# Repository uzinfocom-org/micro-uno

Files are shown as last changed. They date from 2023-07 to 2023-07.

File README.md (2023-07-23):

# Micro UNO

Birinchi mikrokompyuterlar yoki umuman miktoprotsessorlarning qanday ishlashini o'rganmoqchi bo'lsangiz unda ushbu konstruksiya siz uchun ayni muddao. Konstruksiya uchun barcha kerakli ehtiyot qismlarni O'zbekiston sharoitida muammosiz topishingiz mumkin. Shuningdek 3D printerda chop etish uchun modellar ham biriktirilgan.

Youtube video: [https://www.youtube.com/watch?v=Z8Tm94-23g4](https://www.youtube.com/watch?v=Z8Tm94-23g4)

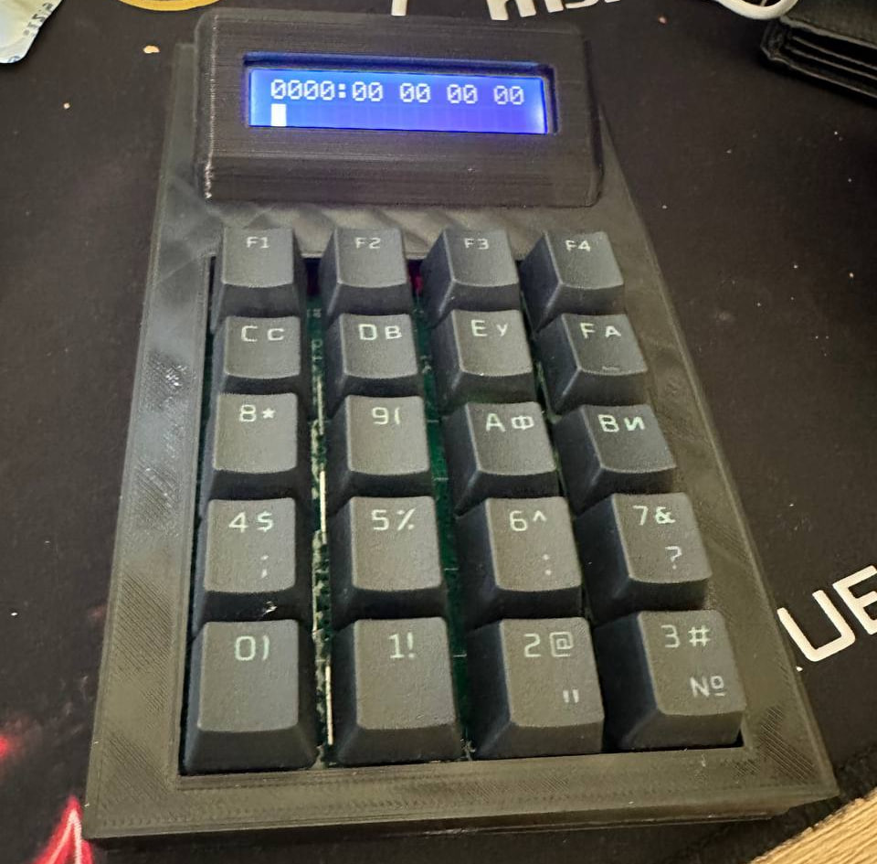
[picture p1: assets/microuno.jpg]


## Talablar

- Atmega328
- UART to USB
- LCD16x2
- Matritsali klaviatura

## Matritsali klaviatura

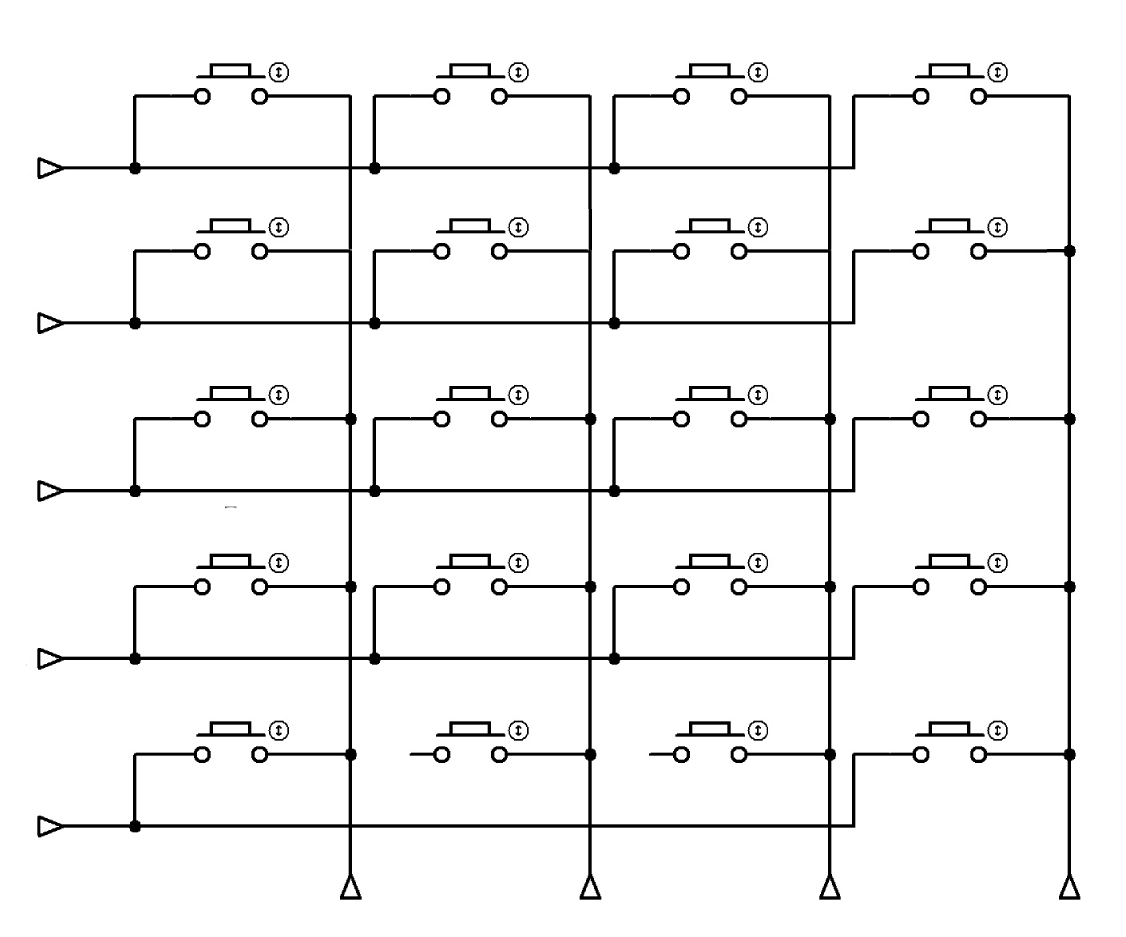
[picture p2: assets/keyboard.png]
Keyborad


## Ishga tushirish va foydalanish

Qurilmada instruksiyalardan foydalanishi uchun 1024Kb dinamik xotira ajratilgan, hozircha dasturlarni ma'lum bir xotiraga saqlash va xotiradan qayta yuklash imkoni mavjud emas (Keyingi versiyalar uchun shinalar bilan ishlash va fayl strukturasi qo'shish rejalashtirilgan).

Har bir seksiyalar to'rt qismdan o'qish va yozish uchun mo'ljallangan:

`0x0000: 00 00 00 00`

Bunda `0x0000` xotira manzili, `00 00 00 00` xotira manzilida yozilgan ma'lumotlar hisoblanadi.

Misol: 0x0000: 01 41 0f 00

```
Manzil - 0x0000, qiymat - 01 // A registerga ma'lumot kiritish
Manzil - 0x0001, qiymat - 58 // ASCII jadvali bo'yicha A registerga kiritilgan X harfi  
Manzil - 0x0002, qiymat - 0f // A registerdan ekranga chiqarish
Manzil - 0x0003, qiymat - 00 // Program counterni tiklash (sikldan chiqish)
```

- Ishga tushirish: `0xffff`
- Qayta ishga tushirish: `0xfffb`
- Ekranni tozalash: `0xfffa`
- Xotira manzilidan o'qish: `0xfffc`
- UART orqali ma'lumotlarni o'qish: `0xfffd`
- Ma'lumotlarni UART orqali saqlash: `0xfffe`

_Barcha instruksiyalar bilan [instruction_set](assets/instruction_set.pdf) fayli orqali tanishingiz mumkin. Shuningdek [samples](samples/)_ papkasida bir necha misollar ham ko'rsatilgan.

## Dasturlarni UART orqali yuklash

Kerakli dasturlarni assembler orqali odatiy matn muharrirda yozib [compiler.php](compiler/compiler.php) dasturi orqali mashina kodiga o'girishingiz va qurilmaga yuklashingiz mumkin. Bu uchun mikrokompyuterdan `fffd` buyrug'i orqali yuklash rejimiga o'tish lozim.

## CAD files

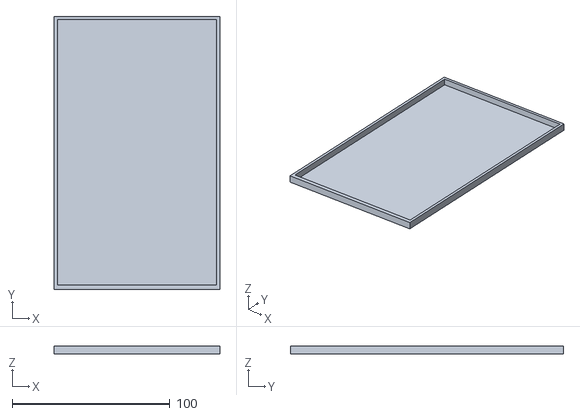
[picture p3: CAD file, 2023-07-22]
3dmodel/back.stl
105.0 x 173.0 x 5.00

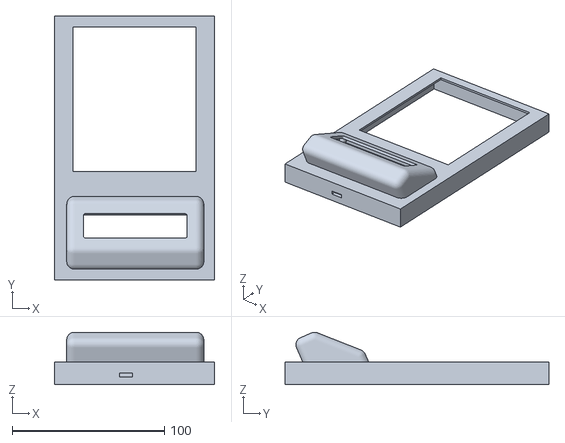
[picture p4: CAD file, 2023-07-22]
3dmodel/front.stl
105.0 x 173.0 x 34.4

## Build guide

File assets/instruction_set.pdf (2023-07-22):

HEX | ASM | ARG | Ta'rif
0x00 | NOP | | no-op, hisoblagichni qayta o'rnatadi
0x01 | LDI | bayt | A registriga ma'lumot yuklash
0x02 | LDA | makros | B registrining ofseti bilan xotira manzilidan A registrga ma'lumot yuklash
0x06 | STA | makros | B registrining ofseti bilan xotira manzilida A registridan qiymatni o'rnatish
0x03 | TAB | | ma'lumotlarni A dan B registriga o'tkazish
0x04 | ADD | bayt | A registriga qiymatni qo'shish va saqlash
0x05 | SUB | bayt | A registridan qiymatni ayrish va saqlash
0x08 | LPC | makros | ma'lumotlarni xotira manzilidan dastur hisoblagichiga yuklash
0x0b | CMP | bayt | Berilgan qiymatni A registr bilan solishtirib natijani nolinchi bayroqga kiritadi
0x0c | JMP | makros | Agarda nolinchi bayroq rost qaytarsa hisoblagichni xotira manziliga o'tkazadi
0x0d | DBG | | Debug ma'lumotlarini serial portga chiqarish
0x28 | SER | | A registrdan serial portga chiqarish
0x07 | RCH | | klaviaturadan belgilarni o'qish (bloklanmaydigan)
0x0e | IN | | klaviaturadan kiritishni A registriga olish (bloklash orqali)
0x10 | BIT | bayt | berilgan qiymatni A registr bilan "bitwise AND" opeatori orqali solishtirish va nolichni bayroqga belgilash
0x11 | AND | bayt | berilgan qiymatni A registr bilan "bitwise AND" opeatori orqali solishtirish va A registerga yozish
0x12 | OR | bayt | berilgan qiymatni A registr bilan "bitwise OR" opeatori orqali solishtirish va A registerga yozish
0x13 | XOR | bayt | berilgan qiymatni A registr bilan "bitwise XOR" opeatori orqali solishtirish va A registerga yozish
0x14 | NOT | bayt | berilgan qiymatni A registr bilan "bitwise NOT" opeatori orqali solishtirish va A registerga yozish
0x15 | SHL | bayt | berilgan qiymatni A registr bilan "bitwise shift left" opeatori orqali solishtirish va A registerga yozish
0x16 | SHR | bayt | berilgan qiymatni A registr bilan "bitwise shift right" opeatori orqali solishtirish va A registerga yozish
0x17 | CLS | | LCD displeyni tozalash
0x0f | OUT | | A registridan LCDga chiqarish
0x18 | SDL | | Displey kontentini chap tomonga nisbatan bir qadam harakatlantiradi
0x19 | SDR | | Displey kontentini o'ng tomonga nisbatan bir qadam harakatlantiradi
0x1a | CRS | | kursorni yoqish (miltillash)
0x1b | NCR | | kursorni o'chirish (miltillamaydi)
0x1c | UDG | | maxsus belgi yaratish (A belgilar identifikatoriga teng (0-7), B bayt massiviga ishora qiladi)
0x1d | SPR | bayt | maxsus belgini chop etish (0-7)
0x1e | POS | | kursor pozitsiyasini belgilash (A ustunga, B qatorga teng)
0x1f | DLY | bayt | bajarilishni kechiktirish
0x20 | RND | bayt | A registriga 0 va argument o'rtasidagi tasodifiy sonni yuklash
0x09 | INC | | B registr qiymatini oshirish
0x0a | DCR | | B registr qiymatini kamaytirish
0x21 | PSH | | A va B registrlarini stekka yuklash
0x22 | POP | | A va B registrlariga stekdan yuklash
0x23 | SBR | makros | Xotira manzilida joylashgan makrosga murojaat qilish
0x24 | RET | | murojaatdan qaytish
0x25 | NUM | makros | (A!=0 DEC, A==0 HEX) raqamni (B==orqadagi 0) xotira manzilida chiqarish
0x26 | INM | makros | xotira manzilidagi qiymatini oshirish
0x27 | DCM | makros | xotira manzilidagi qiymatni kamaytirish

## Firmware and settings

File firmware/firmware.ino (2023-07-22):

#include <avr/pgmspace.h> 
#include <LiquidCrystal_I2C.h>
#include <Keypad.h>

LiquidCrystal_I2C lcd(0x27, 16, 2);

const byte num_rows= 5;
const byte num_cols= 4;

uint8_t keymap[num_rows][num_cols] = {
  {'0','1','2','3'},
  {'4','5','6','7'},
  {'8','9','A','B'},
  {'C','D','E','F'},
  {'R','M','K','L'},
};

byte row_pins[num_rows] = {9, 10, 11, 12, 13};
byte col_pins[num_cols] = {8, 7, 6, 5};


Keypad keypad = Keypad(makeKeymap(keymap), row_pins, col_pins, num_rows, num_cols);

#define MEMORY_SIZE 1024

uint8_t  memory[MEMORY_SIZE];

uint8_t  register_A = 0;
uint8_t  register_B = 0;
uint16_t  program_counter = 0;
uint16_t stack_pointer = 0x3ff;
bool zero_flag = 0;


void reset_memory() {
  for (uint16_t i = 0; i < MEMORY_SIZE; i++)
    memory[i] = 0;
}

uint8_t read_byte() {
  uint8_t value = memory[program_counter];
  program_counter++;
  return value;
}

uint16_t read_word() {
  uint8_t MSB = read_byte();
  uint8_t LSB = read_byte();
  uint16_t value = MSB;
  value <<= 8;
  value |= LSB;
  return value;
}

uint16_t encode_word() {
  uint16_t addr = 0;
  for (int i = 12; i >= 0; i -= 4) {  
    char input = getch();
    if ( input == 'R' ){
      return 0xffff;
    }else if ( input == 'K' ){
      return 0xfffa;
    }else if ( input == 'L' ){
      return 0xfffd;
    }else if ( input == 'M' ){
      return 0xfffc;
    }
    uint8_t hex = ascii_to_hex(input);
    if (i) addr |= hex << i;
    else addr |= hex;
    lcd.print(hex, HEX);
  }
  delay(200);
  return addr;
}

uint8_t encode_byte() {
  uint8_t value = 0;
  for (int i = 4; i >= 0; i -= 4) {  
    char input = getch();
    uint8_t hex = ascii_to_hex(input);
    if (i) value |= hex << i;
    else value |= hex;
    lcd.print(hex, HEX);
  } return value;
}

void print_byte(uint8_t  byte) {
  if (byte<0x10) print_message_lcd(F("0"));
  lcd.print(byte, HEX);
  lcd.print(' ');
}

void print_word(uint16_t  word) {
  uint8_t  MSB = byte(word >> 8);
  uint8_t  LSB = byte(word);
  if (MSB<0x10) { print_message_lcd(F("0")); } lcd.print(MSB,HEX);
  if (LSB<0x10) { print_message_lcd(F("0")); } lcd.print(LSB,HEX);
}

void memory_dump(uint16_t addr) {
  lcd.clear();
  print_word(addr); lcd.print(':');
  for (uint16_t i = addr; i < addr + 4; i++) print_byte(memory[i]);
  lcd.setCursor(0, 1);
}

void print_hex(uint8_t data) {  
  if (data < 0x10) print_message_serial(F("0")); 
  Serial.print(data, HEX);
}

void print_message_lcd(const __FlashStringHelper *message) {
  for (byte i = 0; i < strlen_P((const char*)message); i++) {
    char character = pgm_read_byte_near((const char*)message + i);
    lcd.print(character);
  }
}

void print_message_serial(const __FlashStringHelper *message) {
  for (byte i = 0; i < strlen_P((const char*)message); i++) {
    char character = pgm_read_byte_near((const char*)message + i);
    Serial.print(character);
  }
}

void reset_cpu() {
  register_A = 0;
  register_B = 0;
  program_counter = 0;
  stack_pointer = 0x3ff;
  zero_flag = 0;
}

void execute() {
  while (true) {
    uint8_t opcode = read_byte();    
    
    switch (opcode) {
      case 0x00: program_counter = 0; return;
      case 0x01: zero_flag = ((register_A = read_byte()) == 0); break;
      case 0x02: zero_flag = ((register_A = memory[(read_word() + register_B)]) == 0); break;
      case 0x03: zero_flag = ((register_B = register_A) == 0); break;
      case 0x04: zero_flag = ((register_A += read_byte()) == 0); break;
      case 0x05: zero_flag = ((register_A -= read_byte()) == 0); break;
      case 0x06: memory[read_word() + register_B] = register_A; break;
      case 0x08: program_counter = read_word(); break;
      case 0x09: zero_flag = (++register_B == 0); break;
      case 0x0a: zero_flag = (--register_B == 0); break;
      case 0x0b: zero_flag = ((register_A - read_byte()) == 0); break;
      case 0x0c: if (zero_flag) program_counter = read_word(); else read_word(); break;
      case 0x07: zero_flag = (register_A = keypad.getKey()) == 0; break;
      case 0x0e: while ((register_A = keypad.getKey()) == NO_KEY); break;
      case 0x0f: lcd.print(char(register_A)); break;
      case 0x28: Serial.print(char(register_A)); break;
      case 0x10: zero_flag = ((register_A & read_byte()) == 0); break;
      case 0x11: zero_flag = ((register_A &= read_byte()) == 0); break;
      case 0x12: zero_flag = ((register_A |= read_byte()) == 0); break;
      case 0x13: zero_flag = ((register_A ^= read_byte()) == 0); break;
      case 0x14: zero_flag = ((register_A = ~read_byte()) == 0); break;
      case 0x15: zero_flag = ((register_A <<= read_byte()) == 0); break;
      case 0x16: zero_flag = ((register_A >>= read_byte()) == 0); break;
      case 0x17: lcd.clear(); break;
      case 0x18: lcd.scrollDisplayLeft(); break;
      case 0x19: lcd.scrollDisplayRight(); break;
      case 0x1a: lcd.blink(); break;
      case 0x1b: lcd.noBlink(); break;
      case 0x1e: lcd.setCursor(register_A, register_B); break;
      case 0x1f: delay(read_byte()); break;
      case 0x20: zero_flag = (register_A = random(read_byte())); break;
      case 0x25: lcd.print(memory[read_word()]); break;
      case 0x26: zero_flag = (++memory[read_word()] == 0); break;
      case 0x27: zero_flag = (--memory[read_word()] == 0); break;
      case 0x21:
        memory[stack_pointer--] = register_A;
        memory[stack_pointer--] = register_B;
        break;
      case 0x22:
        register_B = memory[++stack_pointer];
        register_A = memory[++stack_pointer];
        break;
      case 0x23:
        memory[stack_pointer--] = (uint8_t)(program_counter & 0x00ff) + 2;
        memory[stack_pointer--] = (uint8_t)(program_counter >> 4);
        program_counter = read_word();
        break;
      case 0x24:
        program_counter = 0;
        program_counter <<= memory[++stack_pointer];
        program_counter |= memory[++stack_pointer];
        break;
      case 0x1c:
        lcd.createChar(register_A, memory + register_B);
        lcd.begin();
        break;
      case 0x1d: lcd.write(byte(read_byte())); break;
      case 0x0d:
        print_message_serial(F("A register: 0x"));
        Serial.println(register_A, HEX);
        print_message_serial(F("B register: 0x"));
        Serial.println(register_B, HEX);
        print_message_serial(F("Hisoblagich: 0x"));
        Serial.println(program_counter, HEX);
        print_message_serial(F("Stek ko'rsatkichi: 0x"));
        Serial.println(stack_pointer, HEX);
        print_message_serial(F("ZF: 0x"));
        Serial.println(zero_flag, HEX);
        break;
      default:
        lcd.clear();
        print_message_lcd(F("NOMA'LUM OPKOD:"));
        lcd.setCursor(0, 1);
        print_byte(opcode);
        print_message_lcd(F("? "));
        return;
    }
  }
}


char getch() {
  char key;
  while ((key = keypad.getKey()) == NO_KEY) {
      
  }
  return key;
}

uint8_t ascii_to_hex(char ascii) {
  return ascii <= '9' ? (ascii - '0') : (ascii - 'A' + 10);
}

void init_computer() {
  lcd.clear();
  print_message_lcd(F("    MICRO UNO   "));
  lcd.setCursor(0, 1);
  reset_cpu();
  reset_memory();
}

void command_run() {
  lcd.clear();
  print_message_lcd(F("ISHGA TUSHIRISH"));
  lcd.setCursor(3, 2);
  delay(300);
  lcd.clear();
  execute();
}

void command_view() {
  lcd.clear();
  print_message_lcd(F("KO'RISH: "));
  memory_dump(encode_word());
}

void command_load() {
  lcd.clear();
  print_message_lcd(F("Yuklash..."));
  delay(300);
  lcd.clear();
  print_message_lcd(F(" Ma'lumotlar"));
  lcd.setCursor(0, 1);
  print_message_lcd(F("kutilmoqda..."));
  while (Serial.available() == 0);
  lcd.clear();
  print_message_lcd(F("Yuklash..."));
  Serial.readBytes(memory, MEMORY_SIZE);
  
  for (int i = 0; i < MEMORY_SIZE; i++) {
    memory[i] = ascii_to_hex(memory[i]);
    if ((i % 2) == 0) memory[i] <<= 4;
    else {
      memory[i - 1] |= memory[i];
      memory[i] = 0;
    }
  }
  
  for (int i = 0; i < MEMORY_SIZE; i++) {
    if ((i % 2) == 0) {
      if (i) {
        memory[i - ((int)(i / 2))] = memory[i];
        memory[i] = 0;
      }
    }
  }

  print_message_lcd(F("    ok"));
  lcd.setCursor(0, 1);
}

void command_save() {
  lcd.clear();
  print_message_lcd(F("SAQLASH "));
  delay(300);
  lcd.clear();
  print_message_lcd(F("Saqlash..."));
  
  for (int i = 0; i < MEMORY_SIZE; i++) {
    if ( memory[i] < 0x10) print_message_serial(F("0"));
    Serial.print(memory[i], HEX);
  }
  
  print_message_lcd(F("    ok"));
  lcd.setCursor(0, 1);
}

void command_clear() {
  lcd.clear();
  print_message_lcd(F("TOZALASH"));
  delay(300);
  lcd.clear();
}

void command_new() {
  lcd.clear();
  print_message_lcd(F("YANGI  "));
  lcd.setCursor(3, 2);
  delay(300);
  init_computer();
}

void setup() {
  Serial.begin(9600);
  
  lcd.begin();
  lcd.noAutoscroll();
  lcd.blink();
  
  init_computer();
}

void loop() {  
  while (true) {
    uint16_t addr = encode_word();
    lcd.print(':');

    switch (addr) {
      case 0xfffa: command_clear(); break;
      case 0xfffb: command_new(); break;
      case 0xfffc: command_view(); break;
      case 0xfffd: command_load(); break;
      case 0xfffe: command_save(); break;
      case 0xffff: command_run(); break;
      
      default:
        for (uint16_t i = addr; i < addr + 4; i++) {
          memory[i] = encode_byte();
          lcd.print(' ');
        }
        
        delay(300);
        memory_dump(addr);
        break;
    }    
  }
}
